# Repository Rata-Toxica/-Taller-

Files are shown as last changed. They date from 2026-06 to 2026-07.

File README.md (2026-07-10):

# 🌱 Sistema de Monitoreo de Humedad y Recomendación de Riego

Sistema basado en ESP32 que mide la humedad del suelo y determina si es recomendable regar. La información puede visualizarse mediante el monitor serial y transmitirse por Bluetooth, sin depender de una conexión WiFi permanente.

## Integrantes

- Tomás Varela
- Moira San Martín
- Cristian Noemi

## Descripción del proyecto

Este proyecto consiste en un sistema de monitoreo de humedad del suelo orientado a apoyar la decisión de riego.

Un sensor conectado al ESP32 mide el nivel de humedad de la tierra. El programa analiza la lectura obtenida y determina si el suelo se encuentra seco o húmedo. Posteriormente comunica el resultado al usuario mediante Bluetooth y comunicación serial por USB.

La versión final no activa automáticamente el flujo de agua. Su función es informar al usuario si corresponde regar, reduciendo la complejidad eléctrica y evitando depender de una conexión a internet.

## Problema que resuelve

En muchos contextos agrícolas y domésticos, el riego se realiza utilizando horarios fijos o estimaciones visuales, sin medir directamente la humedad del suelo.

Esto puede provocar:

- Riego innecesario.
- Uso excesivo de agua.
- Falta de riego cuando la tierra se encuentra seca.
- Decisiones basadas únicamente en la experiencia del usuario.

El sistema entrega una recomendación basada en una medición real de la humedad del suelo.

## Objetivos

- Medir la humedad del suelo mediante un sensor.
- Diferenciar entre suelo seco y suelo húmedo.
- Informar al usuario si es recomendable regar.
- Transmitir las mediciones mediante Bluetooth.
- Permitir la visualización de los datos mediante comunicación serial USB.
- Reducir la dependencia de redes WiFi en zonas agrícolas.
- Documentar las pruebas y cambios realizados durante el desarrollo.

## Arquitectura del sistema

```text
Sensor de humedad
        │
        ▼
      ESP32
        │
        ├── Bluetooth
        │
        └── Comunicación serial USB
                    │
                    ▼
          Computador o usuario
                    │
                    ▼
        Recomendación de riego
```

## Funcionamiento

1. El sensor de humedad realiza una lectura analógica de la tierra.
2. El ESP32 recibe la lectura mediante el pin GPIO 34.
3. El programa compara la medición con un umbral de referencia.
4. Si la lectura indica tierra seca, el sistema recomienda regar.
5. Si la lectura indica tierra húmeda, el sistema informa que no es necesario regar.
6. Los datos se muestran mediante el monitor serial.
7. La información también puede enviarse mediante Bluetooth.

Durante las pruebas se utilizó un umbral aproximado de `2500`.

- Valores superiores a `2500`: suelo seco.
- Valores iguales o inferiores a `2500`: suelo húmedo.

Este valor puede requerir una nueva calibración dependiendo del sensor, el tipo de tierra y las condiciones de uso.

## Versión final del proyecto

La versión final funciona como un sistema de monitoreo y recomendación de riego.

El dispositivo:

- Mide la humedad del suelo.
- Determina si el suelo está seco o húmedo.
- Comunica el resultado al usuario.
- No activa automáticamente una electroválvula.
- No necesita una conexión WiFi permanente.
- Puede utilizar Bluetooth o comunicación serial USB.

## Evolución del proyecto

La propuesta inicial consideraba:

- Comunicación mediante WiFi.
- Consulta de información climática.
- Uso de una electroválvula.
- Riego automático.
- Alimentación mediante una batería de 9 V.

Durante las primeras pruebas se comprobó que la batería de 9 V no entregaba la energía suficiente para accionar correctamente la electroválvula.

Posteriormente se probó una alimentación de 12 V, pero la electroválvula no funcionó de manera suficientemente confiable con la configuración utilizada.

También se identificó que depender de WiFi podía ser una limitación, ya que en zonas agrícolas o campos alejados no siempre existe una conexión estable.

Por estas razones se decidió:

- Cambiar la comunicación de WiFi a Bluetooth.
- Utilizar comunicación serial USB como alternativa.
- Eliminar la electroválvula de la versión final.
- Transformar el proyecto en un sistema de monitoreo y recomendación de riego.

La evolución completa está documentada en la carpeta [`iteraciones`](./iteraciones).

## Componentes principales

### Componentes de la versión final

- ESP32.
- Sensor de humedad del suelo.
- Protoboard.
- Cables Dupont.
- Fuente de alimentación.
- Computador para visualización y pruebas.
- Encapsulado impreso en 3D.

### Componentes utilizados durante las iteraciones

- Módulo relé de un canal.
- Electroválvula.
- Batería de 9 V.
- Alimentación de 12 V.

Estos componentes fueron utilizados durante las primeras versiones, pero no forman parte del funcionamiento final del sistema.

## Tecnologías utilizadas

- ESP32.
- Arduino IDE.
- C++ para Arduino.
- Biblioteca `BluetoothSerial`.
- Python.
- Comunicación Bluetooth.
- Comunicación serial USB.
- Autodesk Fusion 360.
- GitHub.

## Diseño 3D

Se diseñó un encapsulado simple y funcional para proteger y organizar los componentes electrónicos.

La carpeta [`Modelo 3D`](./Modelo%203D) contiene:

- Archivos editables de Fusion 360 en formato `.f3d`.
- Archivos CAD en formato `.step`.
- Archivos para impresión 3D en formato `.stl`.
- Imágenes con vistas y dimensiones del encapsulado.
- Documentación del diseño.

El modelo no tuvo cambios importantes durante el desarrollo, ya que el diseño inicial cumplía con las funciones necesarias.

## Pruebas realizadas

Las pruebas del sistema incluyeron:

- Lectura del sensor en suelo húmedo.
- Lectura del sensor en suelo seco.
- Evaluación de condiciones antes de recomendar el riego.
- Pruebas de activación realizadas durante las versiones iniciales.
- Comunicación mediante monitor serial.
- Pruebas del montaje físico.
- Pruebas de alimentación.
- Pruebas de comunicación WiFi y Bluetooth.

Las evidencias y resultados están disponibles en la carpeta [`testing`](./testing).

## Instalación y uso

### Requisitos

- Arduino IDE.
- Soporte para placas ESP32 instalado.
- Cable USB compatible con el ESP32.
- Sensor de humedad conectado.
- Computador con Bluetooth, en caso de utilizar esa comunicación.

### Cargar el firmware

1. Descargar o clonar este repositorio.
2. Abrir Arduino IDE.
3. Instalar el soporte para placas ESP32.
4. Abrir el archivo:

```text
Firmware/monitoreo_automatico.ino
```

5. Conectar el ESP32 al computador mediante USB.
6. Seleccionar la placa ESP32 correspondiente.
7. Seleccionar el puerto COM correcto.
8. Cargar el programa al ESP32.
9. Abrir el monitor serial.
10. Configurar la velocidad en `115200` baudios.

### Conexiones principales

- Salida analógica del sensor de humedad: GPIO 34.
- Alimentación del sensor: según las especificaciones del módulo.
- Tierra del sensor: GND del ESP32.

El diagrama completo de conexiones está disponible en la carpeta [`hardware`](./hardware).

### Comunicación Bluetooth

1. Activar Bluetooth en el computador.
2. Encender el ESP32.
3. Buscar el dispositivo:

```text
ESP32_Device
```

4. Vincular el computador con el ESP32.
5. Utilizar una aplicación compatible con comunicación serial Bluetooth.

La comunicación mediante USB serial puede utilizarse como alternativa durante las pruebas.

## Software

La carpeta [`Software`](./Software) contiene archivos desarrollados en Python para experimentar con la recepción, interpretación y almacenamiento de los datos enviados por el ESP32.

Esta parte del proyecto requiere configuración adicional dependiendo del sistema operativo, la conexión Bluetooth y la base de datos utilizada.

## Hardware

La carpeta [`hardware`](./hardware) contiene:

- Diagrama de conexiones.
- Descripción del hardware.
- Lista de materiales.
- Fotografías o representaciones del montaje.
- Información de los componentes utilizados.

## Documentación

La carpeta [`docs`](./docs) contiene:

- Informe del proyecto.
- Manual de usuario.
- Documentación complementaria.

## Estructura del repositorio

```text
-Taller-/
├── Firmware/
│   └── Código del ESP32
│
├── Modelo 3D/
│   ├── Archivos F3D
│   ├── Archivos STEP
│   ├── Archivos STL
│   └── Vistas del encapsulado
│
├── Software/
│   └── Aplicación desarrollada en Python
│
├── docs/
│   └── Informes y manuales del proyecto
│
├── hardware/
│   ├── Diagrama de conexiones
│   ├── Lista de materiales
│   └── Documentación del hardware
│
├── iteraciones/
│   └── Evolución y decisiones de diseño
│
├── testing/
│   └── Protocolos, resultados y evidencias
│
├── .gitignore
├── FUENTES.md
├── LICENSE
└── README.md
```

## Limitaciones

- El sistema final no activa el riego automáticamente.
- El umbral de humedad puede requerir una nueva calibración.
- La comunicación Bluetooth depende de la compatibilidad del computador.
- La versión final no utiliza información climática mediante internet.
- No se implementó una aplicación móvil dedicada.
- La electroválvula fue eliminada debido a problemas de alimentación y funcionamiento.

## Futuras mejoras

- Crear una aplicación móvil.
- Mejorar la estabilidad de la comunicación Bluetooth.
- Agregar una pantalla local.
- Incorporar una batería recargable.
- Implementar gráficos con el historial de mediciones.
- Permitir la configuración del umbral de humedad.
- Reincorporar un sistema de riego automático utilizando una fuente de alimentación adecuada.
- Integrar información climática como una función opcional.
- Permitir la conexión con varios sensores.

## Fuentes

Las librerías, referencias externas, código adaptado y herramientas de inteligencia artificial utilizadas se encuentran declaradas en [`FUENTES.md`](./FUENTES.md).

## Licencia

Este proyecto utiliza la licencia MIT. Consultar el archivo [`LICENSE`](./LICENSE).

## Contexto académico

Proyecto desarrollado para la asignatura Taller de Diseño en Ingeniería de la Universidad Adolfo Ibáñez.

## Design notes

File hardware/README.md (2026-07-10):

# Hardware

Esta carpeta contiene toda la documentación relacionada con el hardware del proyecto.

## Contenido

- Esquemático del circuito.
- Lista de materiales (BOM).
- Fotografías del montaje.
- Diagrama de conexiones.

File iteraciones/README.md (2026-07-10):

# Iteraciones del proyecto

Esta carpeta documenta la evolución del sistema de monitoreo de humedad y recomendación de riego.

Durante el desarrollo se realizaron cambios en la alimentación eléctrica, el método de comunicación y el alcance de la solución. Estas modificaciones surgieron a partir de las pruebas realizadas y de la retroalimentación recibida durante el curso.

## Iteración 1: riego automático con WiFi y batería de 9 V

### Propuesta inicial

La primera versión fue planteada como un sistema de riego automático.

El prototipo incluía:

- ESP32.
- Sensor de humedad del suelo.
- Módulo relé.
- Electroválvula.
- Batería de 9 V.
- Comunicación mediante WiFi.

### Funcionamiento esperado

1. El sensor mediría la humedad del suelo.
2. El ESP32 determinaría si la tierra estaba seca.
3. El sistema consultaría información climática mediante internet.
4. Si las condiciones eran adecuadas, el relé activaría la electroválvula.
5. La electroválvula permitiría el paso del agua.

### Problemas encontrados

Durante las pruebas se comprobó que la batería de 9 V no entregaba la energía suficiente para accionar correctamente la electroválvula.

También se identificó una limitación en el uso de WiFi. Nos dimos cuenta que, en zonas agrícolas o campos alejados, los usuarios no siempre disponen de una conexión WiFi estable.

### Aprendizajes

Esta primera versión permitió comprender que debían considerarse:

- El voltaje requerido por cada componente.
- La corriente necesaria para accionar la electroválvula.
- La disponibilidad real de conectividad en el lugar de uso.
- La dependencia del sistema respecto de internet.

## Iteración 2: alimentación de 12 V

### Objetivo

Resolver el problema energético detectado en la primera versión mediante una fuente de alimentación de 12 V.

### Cambio realizado

Se reemplazó la alimentación de 9 V por una alternativa de 12 V, manteniendo:

- ESP32.
- Sensor de humedad.
- Relé.
- Electroválvula.
- Lógica de riego automático.

### Resultado

A pesar del cambio de alimentación, la electroválvula no funcionó con la configuración utilizada.

El sistema electrónico podía detectar el estado del suelo, pero no se consiguió una activación del mecanismo de agua.

### Decisión

Se determinó que mantener la electroválvula aumentaba la complejidad eléctrica y reducía la confiabilidad del prototipo.

Por esta razón, se decidió eliminar la función de riego automático de la versión final.

## Iteración 3: cambio de WiFi a Bluetooth

### Problema identificado

La propuesta inicial dependía de una red WiFi para transmitir información.

Sin embargo, el sistema estaba pensado para utilizarse en contextos agrícolas, donde muchas veces no existe acceso a WiFi o la conexión puede ser inestable.

### Cambio realizado

Se modificó el método de comunicación:

- Se dejó de depender exclusivamente de WiFi.
- Se incorporó comunicación Bluetooth entre el ESP32 y un computador.
- También se utilizó la conexión USB serial como alternativa durante las pruebas.

### Objetivo del cambio

Permitir que el sistema pudiera transmitir las mediciones a corta distancia sin necesitar una conexión permanente a internet.

### Resultado

El ESP32 fue configurado para enviar los datos de humedad y la recomendación de riego mediante Bluetooth y comunicación serial.

Durante el desarrollo se realizaron ajustes para mejorar la recepción de los datos.

## Iteración 4: sistema de monitoreo y recomendación de riego

### Versión final

La versión final dejó de realizar el riego de forma automática.

El sistema se concentró en:

1. Medir la humedad del suelo.
2. Determinar si el suelo está seco o húmedo.
3. Evaluar las condiciones programadas.
4. Comunicar si es recomendable regar.
5. Mostrar la información mediante el monitor serial y los medios de comunicación implementados.

### Ventajas de la versión final

- Menor consumo energético.
- Menor complejidad eléctrica.
- Mayor seguridad.
- Eliminación del riesgo de activar agua accidentalmente.
- Menor dependencia de internet.
- Mayor facilidad para probar el sistema.
- Mantención del objetivo principal de apoyar la decisión de riego.

## Diseño 3D

El encapsulado 3D no tuvo iteraciones importantes durante el desarrollo.

Desde el inicio se eligió un diseño simple y funcional, orientado a:

- Proteger los componentes.
- Mantener el sistema ordenado.
- Facilitar el acceso a las conexiones.
- Utilizar una tapa desmontable.
- Permitir la fabricación mediante impresión 3D.

Debido a que el diseño cumplía correctamente estas funciones, no fue necesario realizar modificaciones relevantes.

Los archivos editables e imprimibles se encuentran en la carpeta `Modelo 3D`.

## Resumen de las iteraciones

| Iteración | Modificación principal | Resultado |
|---|---|---|
| 1 | Riego automático, WiFi y batería de 9 V | Energía insuficiente y dependencia de WiFi |
| 2 | Alimentación de 12 V | Electroválvula sin funcionamiento confiable |
| 3 | Cambio de WiFi a Bluetooth | Menor dependencia de internet |
| 4 | Eliminación de la electroválvula | Sistema final de monitoreo y recomendación |

## Conclusión

El proyecto evolucionó desde una propuesta de riego automático conectada mediante WiFi hacia un sistema de monitoreo y recomendación de riego con comunicación Bluetooth y serial.

Los cambios realizados respondieron a problemas reales detectados durante las pruebas:

- falta de energía para la electroválvula;
- funcionamiento poco confiable del mecanismo de agua;
- falta de disponibilidad de WiFi en entornos agrícolas.

La versión final mantiene el objetivo de ayudar al usuario a decidir cuándo regar, pero utiliza una solución más simple, segura y coherente con las condiciones del lugar de uso.

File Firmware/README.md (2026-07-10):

# Firmware

## Descripción

Esta carpeta contiene el firmware desarrollado para el ESP32, encargado de controlar el funcionamiento del sistema de monitoreo de humedad y recomendación de riego.

## Funciones principales

- Lectura del sensor de humedad del suelo.
- Consulta de la probabilidad de lluvia mediante la API Open-Meteo.
- Análisis de las condiciones del suelo y del clima.
- Determinación de la recomendación de riego.
- Envío de los datos al servidor Flask.
- Envío de una notificación al dispositivo del usuario mediante Bluetooth.

## Archivo principal

- `riego_automatico.ino`

## Librerías utilizadas

- WiFi.h
- HTTPClient.h
- WiFiClientSecure.h
- ArduinoJson.h
- BluetoothSerial.h

## Plataforma

- ESP32
- Arduino IDE

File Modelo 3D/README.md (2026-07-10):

# Diseño 3D del Encapsulado

Esta carpeta contiene los archivos del encapsulado diseñado para el sistema inteligente de monitoreo de humedad y recomendación de riego.

## Archivos de la caja

- `CajaTaller.f3d`: archivo editable de Autodesk Fusion 360.
- `CajaTaller.step`: modelo CAD compatible con otros programas.
- `CajaTaller.stl`: archivo preparado para impresión 3D.

## Archivos de la tapa

- `TapaTaller.f3d`: archivo editable de Autodesk Fusion 360.
- `TapaTaller.step`: modelo CAD compatible con otros programas.
- `TapaTaller.stl`: archivo preparado para impresión 3D.

## Objetivo del diseño

El encapsulado fue diseñado para proteger y organizar los componentes electrónicos del sistema de riego inteligente.

En su interior se consideran espacios para:

- ESP32.
- Módulo relé.
- Fuente de alimentación.
- Adaptador de conexiones.
- Cableado del sensor de humedad.

El diseño incluye una caja principal, una tapa desmontable y aberturas para las conexiones externas.

## Software utilizado

El modelo fue desarrollado utilizando Autodesk Fusion 360.

## Formatos disponibles

- `.f3d`: archivo editable original de Fusion 360.
- `.step`: archivo CAD compatible con distintos programas.
- `.stl`: archivo utilizado para impresión 3D.

## Unidades

Los modelos fueron diseñados utilizando milímetros.

## Recomendaciones de impresión

- Material recomendado: PETG o PLA.
- Altura de capa sugerida: 0,20 mm.
- Relleno sugerido: entre 15% y 25%.
- Revisar la orientación de la caja y la tapa antes de imprimir.

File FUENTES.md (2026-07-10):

# FUENTES

Este documento declara las librerías, plataformas, herramientas externas y el uso de inteligencia artificial utilizados en el desarrollo del prototipo de **Monitoreo de Humedad y Recomendación de Riego**.

---

# Librerías utilizadas

| Librería | Uso en el proyecto | Fuente |
|---|---|---|
| WiFi.h | Conexión WiFi del ESP32 | Librería incluida en el core de ESP32 para Arduino |
| HTTPClient.h | Envío de datos HTTP desde el ESP32 hacia el servidor Flask | Librería incluida en el core de ESP32 para Arduino |
| WiFiClientSecure.h | Comunicación HTTPS cuando es requerida | Librería incluida en el core de ESP32 para Arduino |
| ArduinoJson.h | Construcción y lectura de mensajes JSON | https://arduinojson.org |
| BluetoothSerial.h | Comunicación Bluetooth con el dispositivo del usuario | Librería incluida en el core de ESP32 para Arduino |
| Flask | Desarrollo del servidor backend y dashboard web | https://flask.palletsprojects.com |
| PyMySQL | Conexión entre Python y MySQL | https://pymysql.readthedocs.io |

---

# Plataformas utilizadas

| Plataforma | Uso en el proyecto |
|---|---|
| Arduino IDE | Desarrollo y carga del firmware del ESP32 |
| Visual Studio Code | Desarrollo del servidor en Python |
| GitHub | Repositorio y control de versiones |
| Aiven MySQL | Base de datos del proyecto |
| Open-Meteo API | Consulta de información climática |
| Fusion 360 | Diseño del encapsulado 3D |
| Canva | Elaboración de la presentación |

---

# Código externo adaptado

No se copió código externo completo desde repositorios de terceros.

Se utilizaron ejemplos generales y documentación oficial sobre:

- Conexión WiFi del ESP32.
- Solicitudes HTTP mediante HTTPClient.
- Desarrollo de aplicaciones con Flask.
- Conexión entre Python y MySQL mediante PyMySQL.
- Consulta de datos mediante Open-Meteo.

Todo el código fue adaptado al proyecto.

---

# Uso de Inteligencia Artificial

## Desarrollo del firmware ESP32

- **Herramienta:** ChatGPT
- **Uso:** Apoyo para desarrollar y depurar el firmware del ESP32.
- **Adaptación:** El código fue ajustado al sensor de humedad, Bluetooth, WiFi y consulta de Open-Meteo.
- **Comprensión:** El equipo comprende el funcionamiento completo del firmware.

## Desarrollo del servidor y dashboard

- **Herramienta:** ChatGPT
- **Uso:** Apoyo en la creación del servidor Flask y dashboard.
- **Adaptación:** El backend fue configurado con Aiven MySQL y adaptado al proyecto.
- **Comprensión:** El equipo comprende el flujo entre ESP32, servidor y base de datos.

## Documentación y organización de GitHub

- **Herramienta:** ChatGPT
- **Uso:** Apoyo en README.md, FUENTES.md y organización del repositorio.
- **Adaptación:** La documentación fue adaptada al proyecto.
- **Comprensión:** El equipo comprende la función de cada archivo y carpeta.

---

# Declaración final

El equipo declara que las herramientas externas e inteligencia artificial fueron utilizadas únicamente como apoyo para acelerar el desarrollo, depuración y documentación del proyecto. Las decisiones técnicas, integración del hardware, desarrollo del software y pruebas fueron realizadas por los integrantes del equipo.

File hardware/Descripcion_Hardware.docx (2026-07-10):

# Descripción del Hardware

El sistema está compuesto por un ESP32 y un sensor de humedad del suelo. El ESP32 procesa las mediciones del sensor, consulta la probabilidad de lluvia mediante la API Open-Meteo y evalúa si es recomendable realizar un riego.

## Funcionamiento

- Lectura continua de la humedad del suelo.
- Consulta automática de condiciones climáticas.
- Evaluación de la necesidad de riego.
- Envío de una recomendación de riego al dispositivo del usuario por Bluetooth.
- Registro de datos para su visualización en el dashboard web.

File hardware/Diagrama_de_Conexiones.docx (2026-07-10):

# Diagrama de conexiones

Proyecto: Sistema Inteligente de Recomendación de Riego

## Conexiones principales

Componente | Pin | Conectado a
Sensor de humedad | VCC | 3.3V ESP32
Sensor de humedad | GND | GND ESP32
Sensor de humedad | AO | GPIO34 (entrada analógica)
ESP32 | USB | Alimentación y programación

## Descripción

El ESP32 lee el valor entregado por el sensor de humedad del suelo. Con esta información y la probabilidad de lluvia obtenida desde Open-Meteo, el sistema determina si se recomienda regar. Cuando corresponde, envía una notificación al dispositivo móvil del usuario mediante Bluetooth.

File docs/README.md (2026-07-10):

# Documentación

Esta carpeta contiene la documentación del proyecto **Sistema Inteligente de Monitoreo de Humedad y Recomendación de Riego**.

## Contenido

- Presentación final del proyecto.
- Manual de usuario.
- Documentación complementaria.

## Descripción

En esta carpeta se almacena la documentación desarrollada durante el proyecto, incluyendo la presentación utilizada para la exposición y el manual de usuario, con el objetivo de facilitar la comprensión del funcionamiento del sistema y su utilización.

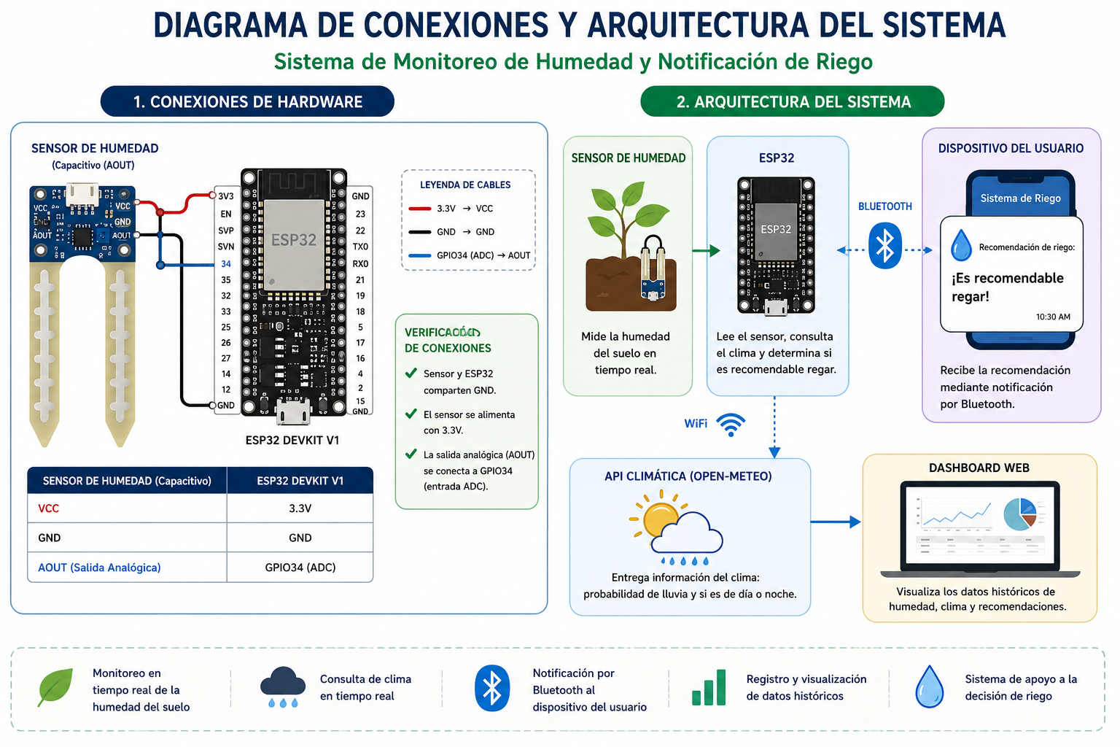
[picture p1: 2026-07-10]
hardware/5763aa2a-0655-4240-b270-e1f14bb6db55.png

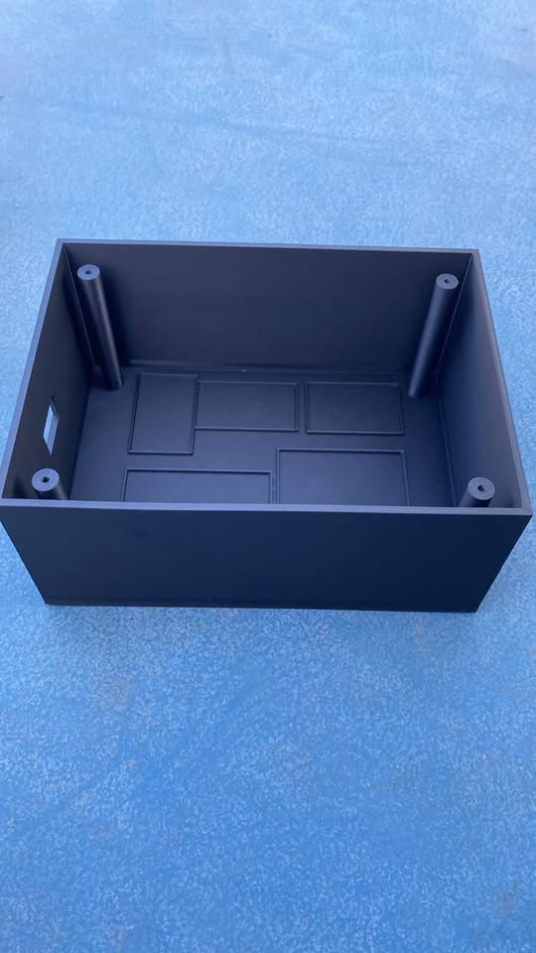
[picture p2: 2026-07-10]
Modelo 3D/VistaExterior.jpg

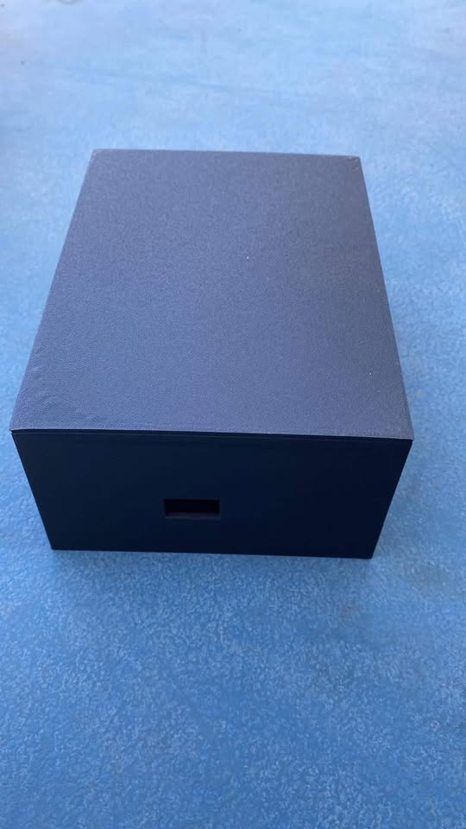
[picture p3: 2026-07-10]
Modelo 3D/VistaAbajo.jpg

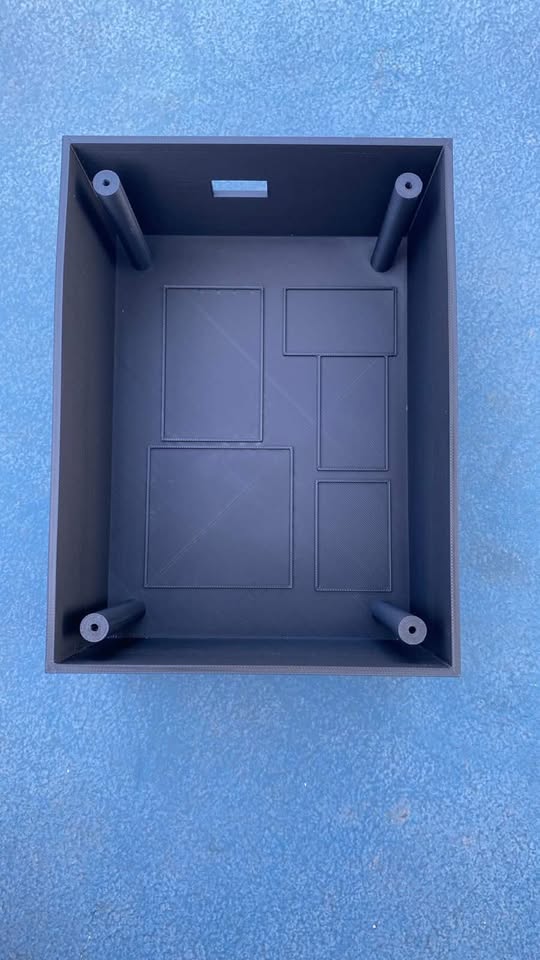
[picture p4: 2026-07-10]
Modelo 3D/VistaInterior.jpg

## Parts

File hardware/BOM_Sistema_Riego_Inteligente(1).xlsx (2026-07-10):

Ítem | Componente | Cantidad | Función
1 | ESP32 | 1 | Microcontrolador principal del sistema
2 | Sensor de humedad del suelo | 1 | Medición de la humedad del suelo
3 | Módulo relé de 1 canal | 1 | Control del sistema durante el desarrollo
4 | Cables Dupont | 10 | Conexión entre componentes
5 | Cable USB | 1 | Programación y alimentación del ESP32
6 | Computador | 1 | Ejecución del servidor Flask y dashboard

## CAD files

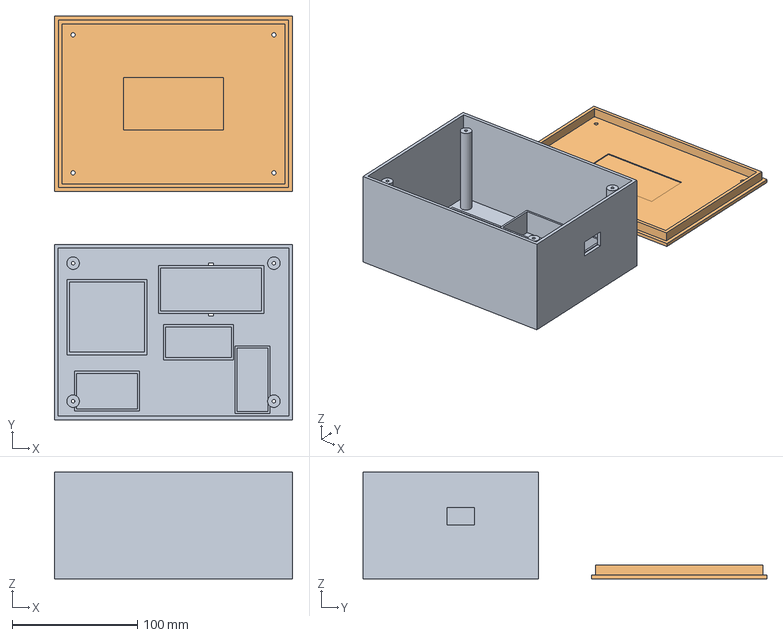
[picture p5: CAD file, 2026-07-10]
Modelo 3D/CajaTaller.step
190.0 x 322.0 x 85.0 mm
base
lid

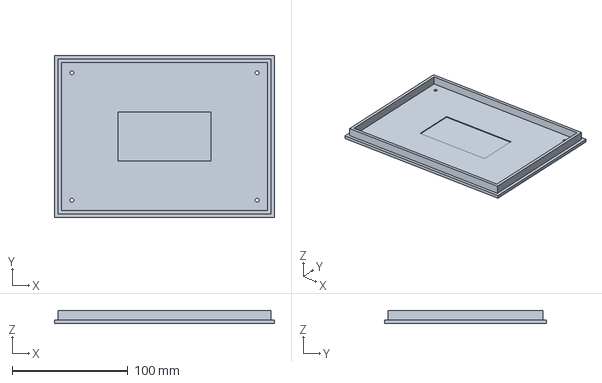
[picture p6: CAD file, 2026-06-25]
Modelo 3D/TapaTaller.step
190.0 x 140.0 x 11.0 mm

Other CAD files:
Modelo 3D/CajaTaller.f3d
Modelo 3D/CajaTaller.stl
Modelo 3D/TapaTaller.f3d
Modelo 3D/TapaTaller.stl

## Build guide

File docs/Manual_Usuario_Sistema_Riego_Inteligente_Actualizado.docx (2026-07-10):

# Manual de Usuario

Sistema Inteligente de Monitoreo de Humedad y Recomendación de Riego

## 1. Descripción

Este sistema monitorea la humedad del suelo mediante un ESP32 y un sensor de humedad. Además, consulta la probabilidad de lluvia utilizando la API Open-Meteo para determinar si las condiciones del suelo y del clima hacen recomendable realizar un riego. El sistema envía una notificación al dispositivo del usuario mediante Bluetooth, registra cada medición en una base de datos y permite visualizar el historial en un dashboard web.

## 2. Requisitos

- ESP32 programado con el firmware del proyecto.
- Sensor de humedad del suelo conectado al ESP32.
- Computador con Python y Flask instalados.
- Conexión WiFi para el ESP32 y el servidor.
- Dispositivo con Bluetooth para recibir las notificaciones.

## 3. Puesta en marcha

1. Conectar el ESP32 al computador mediante un cable USB.
2. Ejecutar el servidor con el comando: py app.py.
3. Verificar que Flask esté ejecutándose en el puerto 5000.
4. Abrir el dashboard desde el navegador.
5. Esperar a que el ESP32 envíe las mediciones automáticamente.

## 4. Funcionamiento del sistema

- Lee continuamente la humedad del suelo.
- Consulta la probabilidad de lluvia mediante la API Open-Meteo.
- Analiza las condiciones del suelo y del clima.
- Determina si se recomienda realizar un riego.
- Envía una notificación al dispositivo del usuario mediante Bluetooth.
- Registra las mediciones en la base de datos.
- Actualiza el dashboard con el historial y la recomendación de riego.

## 5. Dashboard

El dashboard permite visualizar:

- Historial de mediciones.
- Humedad del suelo.
- Probabilidad de lluvia.
- Estado del suelo.
- Recomendación de riego.
- Fecha y hora de cada registro.

## 6. Recomendaciones de uso

- Mantener el ESP32 conectado a la red WiFi.
- Verificar periódicamente el estado del sensor de humedad.
- Mantener el servidor Flask en ejecución mientras el sistema esté en uso.
- Revisar las notificaciones para apoyar la decisión de riego.

## 7. Conclusión

El sistema entrega información en tiempo real para apoyar la toma de decisiones sobre el riego, integrando sensores, datos meteorológicos y un dashboard de visualización en una solución IoT.

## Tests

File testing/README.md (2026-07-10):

# Pruebas y validación del sistema

Esta carpeta contiene evidencias y resultados de las pruebas realizadas al sistema inteligente de monitoreo de humedad y recomendación de riego.

## Evidencias disponibles

### 1. Montaje general del sistema

Archivo: `montaje_general.jpg`

Esta imagen muestra el montaje completo del prototipo, incluyendo:

- bolsa con tierra,
- sensor de humedad,
- relé,
- electroválvula (fue eliminada del proyecto),
- cableado,
- conexión al computador.

### 2. Sensor de humedad en la tierra

Archivo: `sensor_en_tierra.jpg`

Esta imagen muestra la instalación física del sensor dentro de la tierra utilizada para las pruebas.

## Pruebas realizadas

### 1. Detección de suelo húmedo

Archivo: `prueba_suelo_humedo.jpg`

**Resultado observado:**

- Humedad medida: 283
- El sistema indica: `Suelo humedo: no se riega`

**Conclusión:**

El sistema detectó correctamente una condición de suelo húmedo y decidió no activar el riego.

### 2. Detección de suelo seco sin activación de riego por baja luz

Archivo: `prueba_suelo_seco_sin_riego.jpg`

**Resultado observado:**

- Humedad medida: 3071
- Luz medida: 192
- El sistema indica: `Suelo seco`
- El sistema indica: `No riega: ya se puso el sol / hay poca luz`

**Conclusión:**

El sistema detectó correctamente el suelo seco, pero no activó el riego porque la condición de luz no era adecuada.

### 3. Activación del riego

Archivo: `prueba_riego_exitoso.jpg`

**Resultado observado:**

- Humedad medida: 3191
- El sistema indica: `Suelo seco`
- El sistema indica: `Condiciones correctas: se riega`
- Luego muestra: `>>> REGANDO <<<`
- Finalmente: `Riego terminado`

**Conclusión:**

El sistema detectó correctamente una condición de suelo seco y activó el riego cuando se cumplieron las condiciones necesarias.

## Resumen de validación

Las pruebas realizadas permitieron comprobar que el sistema:

- detecta diferencias entre suelo húmedo y suelo seco,
- evalúa condiciones adicionales antes de regar,
- activa el riego cuando corresponde,
- registra mensajes de control mediante el monitor serial.

## Observaciones

Durante algunas pruebas se presentaron mensajes relacionados con la conexión WiFi, por ejemplo:

- `No se pudo conectar al WiFi`
- `WiFi desconectado. Reintentando...`
- 
  Esto indica que la conectividad WiFi aún requería ajustes durante el desarrollo, pero no impidió validar la lógica principal del sistema de riego.

## Galería de evidencias

### Montaje general

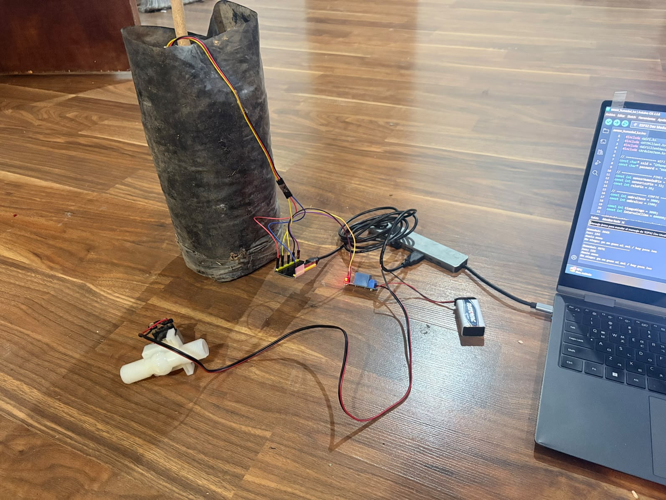
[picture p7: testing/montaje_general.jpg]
Montaje general


### Sensor en la tierra

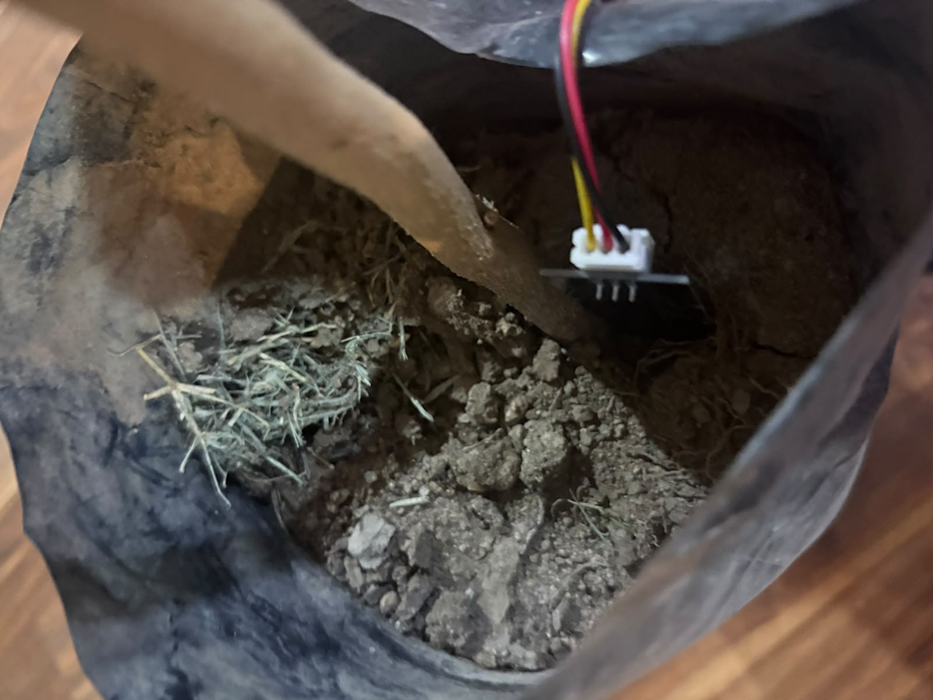
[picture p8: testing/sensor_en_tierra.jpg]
Sensor en la tierra


### Prueba de suelo húmedo

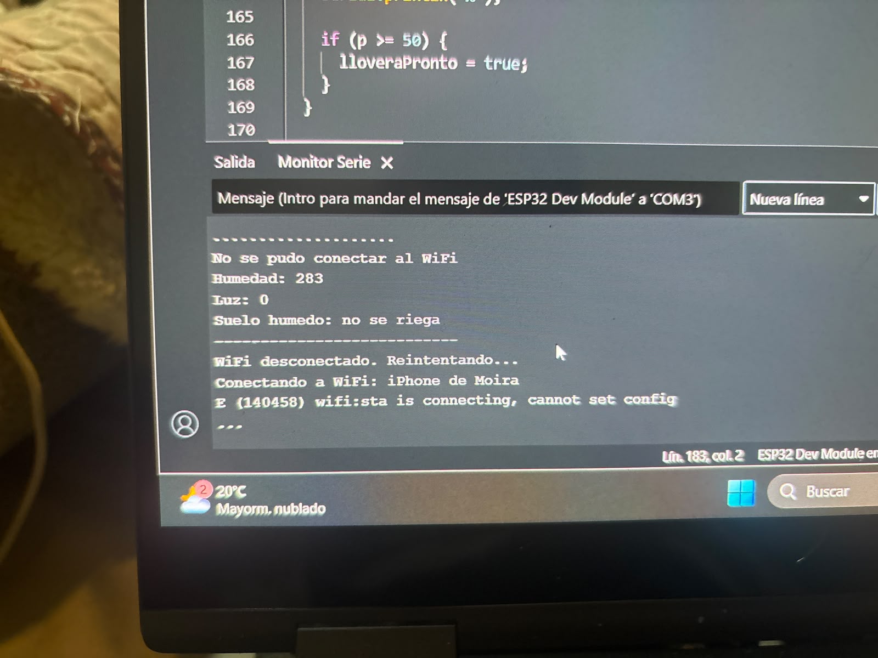
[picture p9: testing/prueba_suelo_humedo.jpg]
Prueba suelo húmedo


### Prueba de suelo seco sin riego

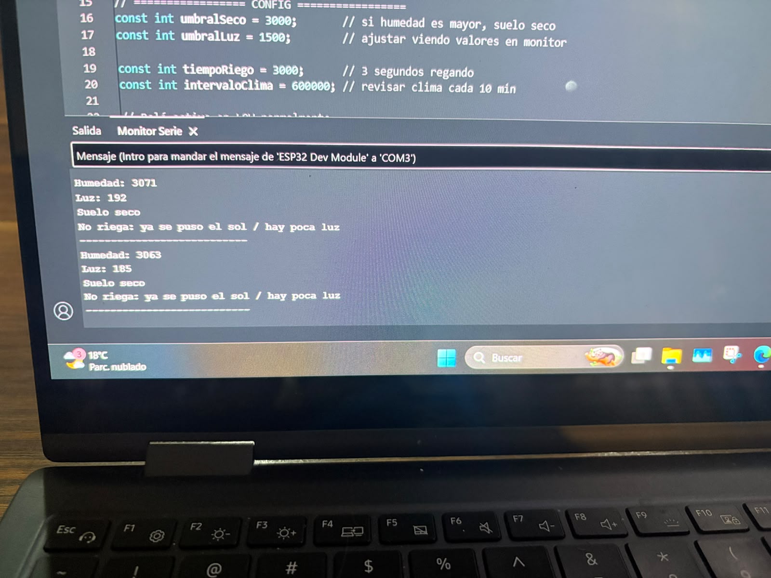
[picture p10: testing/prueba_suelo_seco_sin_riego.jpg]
Prueba suelo seco sin riego


### Prueba de riego exitoso

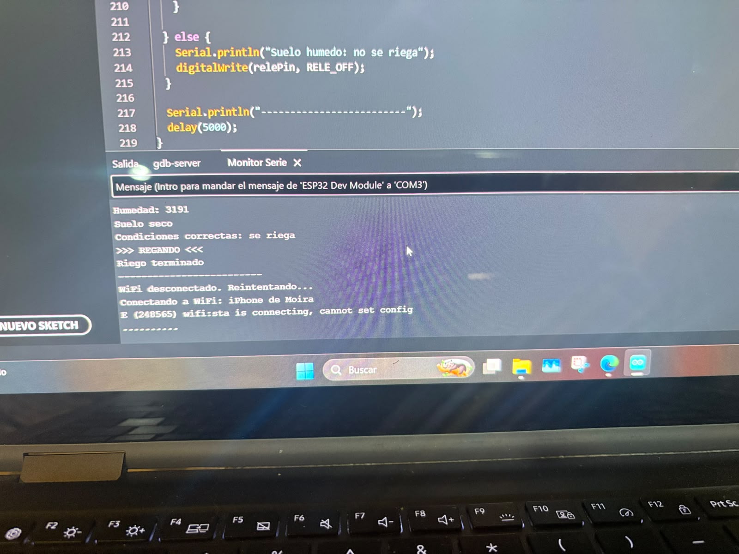
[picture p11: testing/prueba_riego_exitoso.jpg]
Prueba riego exitoso


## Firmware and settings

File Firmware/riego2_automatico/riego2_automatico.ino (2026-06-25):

#include <WiFi.h>
#include <HTTPClient.h>
#include <WiFiClientSecure.h>
#include <ArduinoJson.h>

// =======================
// WIFI
// =======================
const char* ssid = "iPhone de Moira";
const char* password = "66666666";

// =======================
// PINES
// =======================
const int sensorPin = 34;   // Sensor humedad: AOUT -> G34
const int relePin = 26;     // Relé: IN -> G26

// =======================
// UBICACION
// Santiago de Chile aprox.
// =======================
float latitude = -33.45;
float longitude = -70.66;

// =======================
// CONFIGURACION
// =======================
int umbralSeco = 2500;          // Ajustar según prueba del sensor
int probLluviaLimite = 50;      // Si probabilidad lluvia >= 50%, no riega
int tiempoRiegoMs = 3000;       // Riega 3 segundos

// Relé activo en LOW
const int RELE_ON = LOW;
const int RELE_OFF = HIGH;

// =======================
// VARIABLES
// =======================
bool lloveraPronto = false;
bool esDeDia = true;

unsigned long ultimoChequeoClima = 0;
unsigned long intervaloClima = 600000; // 10 minutos

// =======================
// CONECTAR WIFI
// =======================
void conectarWiFi() {
  Serial.print("Conectando a WiFi: ");
  Serial.println(ssid);

  WiFi.begin(ssid, password);

  int intentos = 0;

  while (WiFi.status() != WL_CONNECTED && intentos < 40) {
    delay(500);
    Serial.print(".");
    intentos++;
  }

  Serial.println();

  if (WiFi.status() == WL_CONNECTED) {
    Serial.println("WiFi conectado");
    Serial.print("IP: ");
    Serial.println(WiFi.localIP());
  } else {
    Serial.println("No se pudo conectar al WiFi");
  }
}

// =======================
// CONSULTAR API CLIMA
// =======================
void consultarClima() {
  if (WiFi.status() != WL_CONNECTED) {
    Serial.println("No hay WiFi, no se consulta clima");
    return;
  }

  WiFiClientSecure client;
  client.setInsecure();

  HTTPClient http;

  String url = "https://api.open-meteo.com/v1/forecast?latitude=" + String(latitude, 6) +
               "&longitude=" + String(longitude, 6) +
               "&hourly=precipitation_probability,is_day" +
               "&forecast_hours=6" +
               "&timezone=auto";

  Serial.println("Consultando clima...");
  Serial.println(url);

  http.begin(client, url);
  int code = http.GET();

  if (code != 200) {
    Serial.print("Error al consultar clima. Codigo: ");
    Serial.println(code);
    http.end();
    return;
  }

  DynamicJsonDocument doc(12000);
  DeserializationError error = deserializeJson(doc, http.getStream());

  if (error) {
    Serial.print("Error leyendo JSON: ");
    Serial.println(error.c_str());
    http.end();
    return;
  }

  JsonArray lluvia = doc["hourly"]["precipitation_probability"];
  JsonArray dia = doc["hourly"]["is_day"];

  lloveraPronto = false;

  Serial.println("Probabilidad de lluvia proximas 6 horas:");

  for (int i = 0; i < 6; i++) {
    int prob = lluvia[i];

    Serial.print("Hora ");
    Serial.print(i);
    Serial.print(": ");
    Serial.print(prob);
    Serial.println("%");

    if (prob >= probLluviaLimite) {
      lloveraPronto = true;
    }
  }

  if (dia.size() > 0) {
    esDeDia = (dia[0] == 1);
  }

  Serial.print("Llovera pronto: ");
  Serial.println(lloveraPronto ? "SI" : "NO");

  Serial.print("Es de dia: ");
  Serial.println(esDeDia ? "SI" : "NO");

  http.end();
}

// =======================
// REGAR
// =======================
void regar() {
  Serial.println(">>> REGANDO <<<");

  digitalWrite(relePin, RELE_ON);
  delay(tiempoRiegoMs);
  digitalWrite(relePin, RELE_OFF);

  Serial.println("PRUEBA NUEVO CODIGO");

  Serial.println("Riego terminado");
}

void enviarDatos(
  int humedad,
  int probabilidad_lluvia,
  bool es_dia,
  bool suelo_seco,
  bool riego,
  int duracion
)
{
  if (WiFi.status() != WL_CONNECTED) {
    Serial.println("Sin WiFi");
    return;
  }

  HTTPClient http;

  http.begin("http://172.20.10.14:5000/guardar");
  http.addHeader("Content-Type", "application/json");

  String json = "{";
  json += "\"humedad\":" + String(humedad) + ",";
  json += "\"probabilidad_lluvia\":" + String(probabilidad_lluvia) + ",";
  json += "\"es_dia\":" + String(es_dia ? 1 : 0) + ",";
  json += "\"suelo_seco\":" + String(suelo_seco ? 1 : 0) + ",";
  json += "\"riego\":" + String(riego ? 1 : 0) + ",";
  json += "\"duracion\":" + String(duracion);
  json += "}";

  Serial.println(json);

  int codigo = http.POST(json);

  Serial.print("HTTP: ");
  Serial.println(codigo);

  String respuesta = http.getString();

  Serial.print("Respuesta: ");
  Serial.println(respuesta);

  http.end();
}

// =======================
// SETUP
// =======================
void setup() {
  Serial.begin(115200);
  delay(1000);

  pinMode(relePin, OUTPUT);
  digitalWrite(relePin, RELE_OFF);

  analogReadResolution(12); // lectura 0 a 4095

 conectarWiFi();
// consultarClima();

//enviarDatos(
  //  humedad,
  //  lloveraPronto ? 50 : 0,
   // esDeDia,
    //sueloSeco,
    //seRiego,
  //  seRiego ? tiempoRiegoMs : 0
//);
}

// =======================
// LOOP
// =======================
void loop() {
  if (WiFi.status() != WL_CONNECTED) {
    Serial.println("WiFi desconectado. Reintentando...");
    conectarWiFi();
  }

  if (millis() - ultimoChequeoClima > intervaloClima) {
    ultimoChequeoClima = millis();
    consultarClima();
  }

  int humedad = analogRead(sensorPin);

  bool sueloSeco = humedad > umbralSeco;
  bool seRiego = false;

  Serial.print("Humedad: ");
  Serial.println(humedad);

  if (humedad > umbralSeco) {
    Serial.println("Suelo seco");

    if (!esDeDia) {
      Serial.println("No riega: ya se puso el sol");
    } 
    else if (lloveraPronto) {
      Serial.println("No riega: llovera pronto");
    } 
    else {
      Serial.println("Condiciones correctas: se riega");
      regar();
      seRiego = true;
    }

  } else {
    Serial.println("Suelo humedo: no se riega");
    digitalWrite(relePin, RELE_OFF);
  }

  if (sueloSeco && esDeDia && !lloveraPronto) {
  seRiego = true;
}

  enviarDatos(
  humedad,
  lloveraPronto ? 50 : 0,
  esDeDia,
  sueloSeco,
  seRiego,
  seRiego ? tiempoRiegoMs : 0
);

  Serial.println("-------------------------");
  delay(5000);

}

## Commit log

2026-07-10 Add Bluetooth data handling and database insertion
    Implement Bluetooth data reception and database storage.
2026-07-10 Add USB print for JSON data in enviarDatos function
    Added a print statement to send JSON data via USB for debugging.
2026-07-10 Agrega gitignore para proteger credenciales y archivos temporales
2026-07-10 Mejorar README con detalles de pruebas y resultados
    Actualización del contenido para reflejar mejor las pruebas y resultados del sistema de monitoreo de humedad y riego.
2026-07-10 Documenta cambios de alimentación, comunicación y alcance del proyecto
